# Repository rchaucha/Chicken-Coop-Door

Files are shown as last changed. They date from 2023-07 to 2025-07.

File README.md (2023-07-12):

# Chicken-Coop-Door
Automatic chicken coop door that opens and closes depending on the sun.\
Works on battery on an Arduino Pro Mini 3.3V.

Everything has been done to maximize the battery life :
* The L298N driver board and the photocell are only powered when needed
* The Arduino Pro Mini is put into deep sleep mode almost all the time

Here is the daily routine (beginning with closed door):
1. Every 10 minutes, wake up the Arduino to check if the ambiant light is above a certain threshold (`DAY_THRESHOLD`).
2. Open the door and deep sleep for several hours (~6-7).
3. Wake up the Arduino every 10 minutes to check if the light is below another threshold (`NIGHT_THRESHOLD`).
4. Close the door and deep sleep for several hours.
5. Repeat.

## Dependency
You have to install the Low Power library : https://github.com/rocketscream/Low-Power.

## Schematics
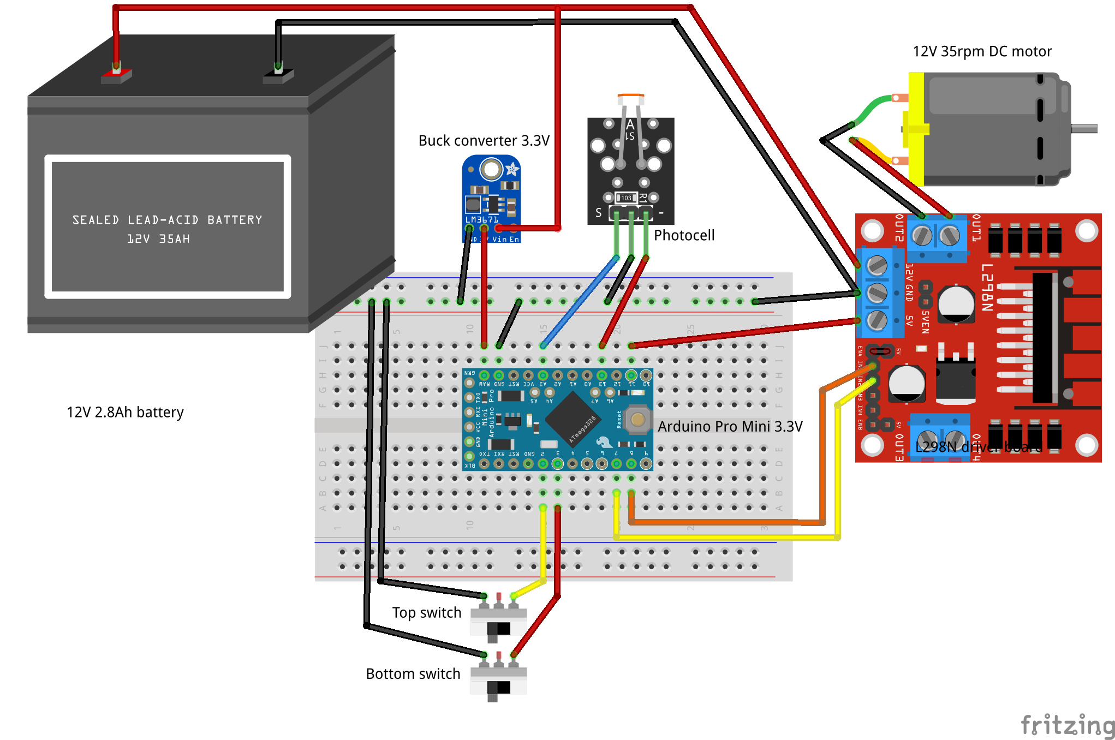
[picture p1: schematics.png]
schematics


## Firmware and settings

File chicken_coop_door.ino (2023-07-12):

#include <LowPower.h>

const int NIGHT_THRESHOLD = 3;
const int DAY_THRESHOLD = 30;

const int photocell_input_pin = A3;
const int mot_up_pin = 7;
const int mot_down_pin = 8;

const int power_L298N_pin = 11;
const int power_photocell_pin = 13;

const int top_switch_pin = 2;
const int bottom_switch_pin = 3;

enum DOOR_OPERATION
{
  OPEN,
  CLOSE
};


///////////////////// FUNCTIONS /////////////////////

void quick_wait()
{
  LowPower.powerDown(SLEEP_250MS, ADC_OFF, BOD_OFF);
}

void deep_sleep(int nb_minutes)
{
  int nb_seconds = 60 * nb_minutes;
  for (int s = 0 ; s < nb_seconds; s += 8) {
    LowPower.powerDown(SLEEP_8S, ADC_OFF, BOD_OFF);
  }
}

int get_light_level()
{
  digitalWrite(power_photocell_pin, HIGH);

  quick_wait();
  int photocell_value = analogRead(photocell_input_pin);

  digitalWrite(power_photocell_pin, LOW);

  return photocell_value;
}

void power_L298N()
{
  digitalWrite(power_L298N_pin, HIGH);
  quick_wait();
}

void stop_motor()
{
  // Stop the motor
  digitalWrite(mot_down_pin, LOW);
  digitalWrite(mot_up_pin, LOW);

  // Turn off L298N
  digitalWrite(power_L298N_pin, LOW);
}

void activate_door(const DOOR_OPERATION op)
{
  power_L298N();

  int switch_pin = 0;

  switch (op)
  {
    case OPEN :
      digitalWrite(mot_up_pin, HIGH);
      digitalWrite(mot_down_pin, LOW);
      switch_pin = top_switch_pin;
      break;
    case CLOSE :
      digitalWrite(mot_up_pin, LOW);
      digitalWrite(mot_down_pin, HIGH);
      switch_pin = bottom_switch_pin;
      break;
  }

  // Continue until the end switch is reached
  while (!digitalRead(switch_pin)) {}

  stop_motor();

  // Wait 7 hours
  deep_sleep(7 * 60);
}


///////////////////// PROGRAM /////////////////////

void setup()
{
  pinMode(mot_down_pin, OUTPUT);
  pinMode(mot_up_pin, OUTPUT);

  pinMode(power_L298N_pin, OUTPUT);
  pinMode(power_photocell_pin, OUTPUT);

  pinMode(top_switch_pin, INPUT_PULLUP);
  pinMode(bottom_switch_pin, INPUT_PULLUP);
}

void loop()
{
  int photocell_value = get_light_level();

  // If the door is not opened and the light is above the day threshold
  if (photocell_value > DAY_THRESHOLD && !digitalRead(top_switch_pin))
  {
    activate_door(DOOR_OPERATION::OPEN);
  }
  // If the door is not closed and the light is below the night threshold
  else if (photocell_value < NIGHT_THRESHOLD && !digitalRead(bottom_switch_pin))
  {
    activate_door(DOOR_OPERATION::CLOSE);
  }

  // Wait 10 minutes
  deep_sleep(10);
}

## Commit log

2022-10-18 Add schematics
2022-10-18 Rename Fritzing file
    [schematics.fzz]
2022-10-18 Add schematics and details
2023-07-12 Fix switch pins inversion, lower day threshold and clean code
    [chicken_coop_door.ino]
2024-04-28 Update schematics to power arduino with 12V battery and increase readibility
    [schematics.fzz]
2025-07-28 Update schematics with buck converter
    [schematics.fzz]
